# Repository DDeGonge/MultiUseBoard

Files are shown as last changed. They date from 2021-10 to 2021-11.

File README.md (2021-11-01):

# MultiUseBoard
The MUB - An ultra-compact, modular processing unit

## What is it?
A tiny, modular, all-in-one processing board. On it's own, it can't do much. But this board can be integrated into just about any other board. All of the mcu pins and power lines are accessible through the low-profile connectors, providing the maximum mcu potential for any project.

## So what makes this better than an Arduino/Blue Pill/Feather?
Well, a few reasons...
- Super compact 32mm x 23mm size
- Powerful Cortex M4 120MHz mcu
- Access to EVERY SINGLE PIN (41 total GPIO)
- Super tiny and low profile board-board connectors
- Onboard 5v and 3v3 regulators (Supports up to 32V input)
- $10 BOM cost at qty 1, $7 at qty 10
- Broken out programming header for easy access

## Cool, I want one!
Great! Then build it yourself :) I hope to sell these boards once the global chip shortage resolves itself, but for now you are on your own!

The gerber files to order the board are found in this repo. Order at your own risk.

A probably up-to-date BOM can be found [here](https://octopart.com/bom-tool/H8oUqADt)

A custom package for kicad exists in the libraries folder, so you can easily integrate the mounting footprint into your own board and simply connect a MUB in the slot.

Godspeed.

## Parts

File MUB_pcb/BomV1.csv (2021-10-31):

Id | Designator | Package | Quantity | Designation | Supplier and ref
1 | J3 | PinHeader_1x05_P1.27mm_Vertical | 1 | Conn_01x05
2 | R3 | R_0402_1005Metric | 1 | 0
3 | G*** | logo_v1 | 1 | LOGO
4 | C35,C12,C36,C2 | C_0805_2012Metric | 4 | 10uF
5 | C13,C3,C11,C10,C7 | C_0603_1608Metric | 5 | 1uF
6 | C8,C25,C9,C6,C5,C4,C1 | C_0603_1608Metric | 7 | 100nF
7 | R15,R1,R2 | R_0603_1608Metric | 3 | 10k
8 | J4 | AMPHENOL_10118194-0001LF | 1 | 10118194-0001LF
9 | IC2 | QFN-64-1EP_9x9mm_P0.5mm_EP6x6mm | 1 | ATSAMD51J19A-MU
10 | J2,J1 | DF40C40DP04V51 | 2 | DF40C-40DP-0.4V_51_
11 | S1 | KMR421GULCLFS | 1 | KMR243GLFG
12 | R20,R19,R17 | R_0603_1608Metric | 3 | 174
13 | D2,D1 | LED_0603_1608Metric | 2 | LED
14 | Y1 | LFXTAL009678REEL | 1 | LFXTAL009678REEL
15 | U3 | SOT-23-5 | 1 | AP2112K-3.3
16 | R18,R16 | R_0603_1608Metric | 2 | 2k2
17 | L3,L2,L1 | L_0805_2012Metric | 3 | 10uH
18 | IC1 | SOT95P280X100-6N | 1 | AP63205WU-7
19 | D5 | D_SOD-123F | 1 | CGRTS4004-HF
20 | C33,C32 | C_0603_1608Metric | 2 | 12pF

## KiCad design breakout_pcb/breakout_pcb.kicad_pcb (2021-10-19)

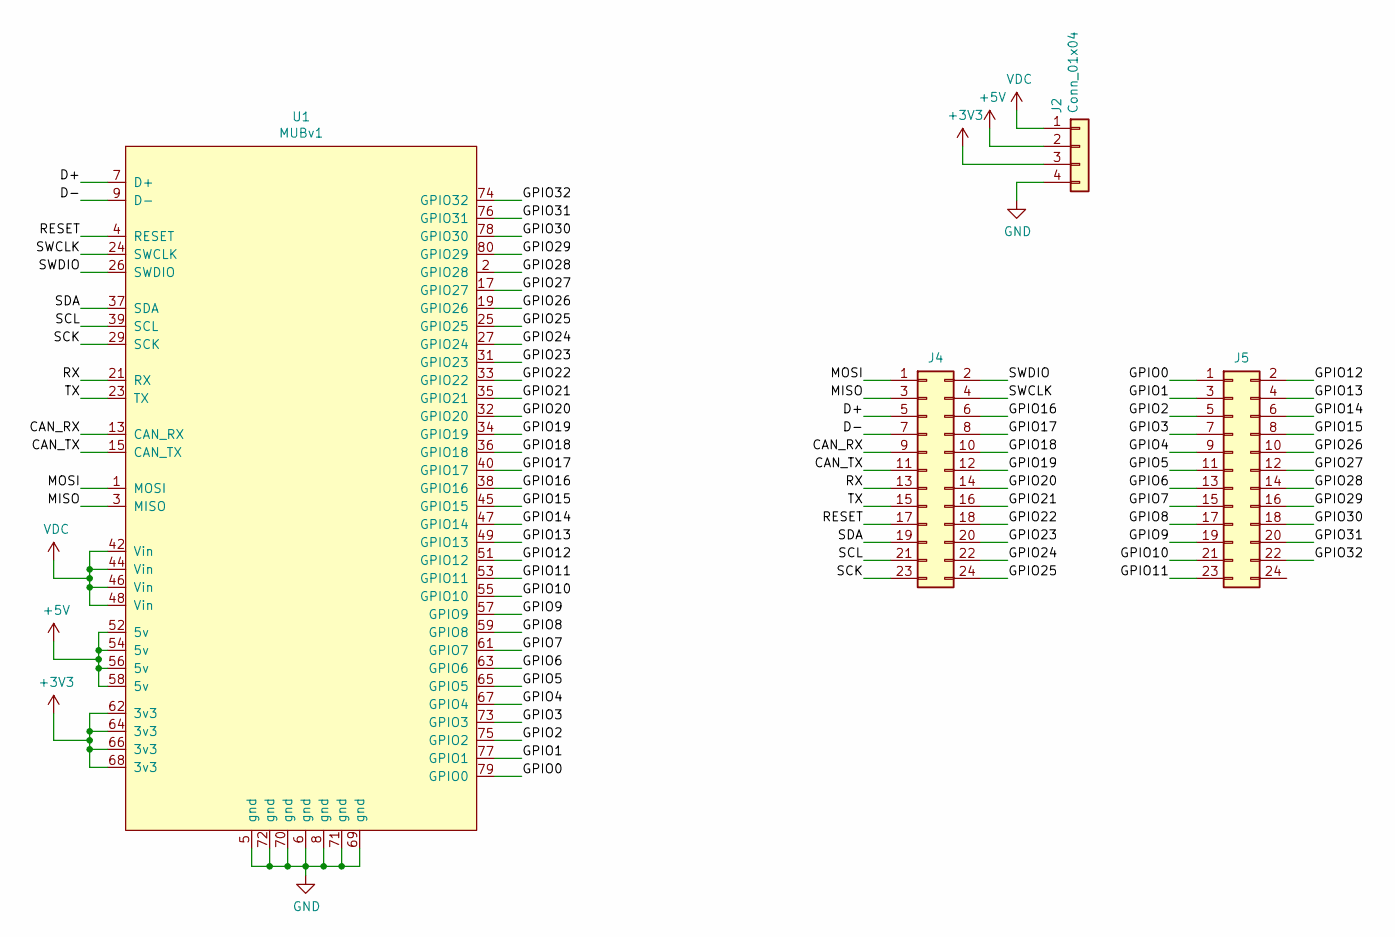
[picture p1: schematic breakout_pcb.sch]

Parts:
J2: Conn_01x04; PinSocket_1x04_P2.54mm_Vertical
J4, J5: Conn_02x12_Odd_Even; PinSocket_2x12_P2.54mm_Vertical
U1: MUBv1; MUB_v1

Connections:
+3V3: J2.3, U1.62 (3v3), U1.64 (3v3), U1.66 (3v3), U1.68 (3v3)
+5V: J2.2, U1.52 (5v), U1.54 (5v), U1.56 (5v), U1.58 (5v)
/CAN_RX: J4.9, U1.13 (CAN_RX)
/CAN_TX: J4.11, U1.15 (CAN_TX)
/D+: J4.5, U1.7 (D+)
/D-: J4.7, U1.9 (D-)
/GPIO0: J5.1, U1.79 (GPIO0)
/GPIO1: J5.3, U1.77 (GPIO1)
/GPIO2: J5.5, U1.75 (GPIO2)
/GPIO3: J5.7, U1.73 (GPIO3)
/GPIO4: J5.9, U1.67 (GPIO4)
/GPIO5: J5.11, U1.65 (GPIO5)
/GPIO6: J5.13, U1.63 (GPIO6)
/GPIO7: J5.15, U1.61 (GPIO7)
/GPIO8: J5.17, U1.59 (GPIO8)
/GPIO9: J5.19, U1.57 (GPIO9)
/GPIO10: J5.21, U1.55 (GPIO10)
/GPIO11: J5.23, U1.53 (GPIO11)
/GPIO12: J5.2, U1.51 (GPIO12)
/GPIO13: J5.4, U1.49 (GPIO13)
/GPIO14: J5.6, U1.47 (GPIO14)
/GPIO15: J5.8, U1.45 (GPIO15)
/GPIO16: J4.6, U1.38 (GPIO16)
/GPIO17: J4.8, U1.40 (GPIO17)
/GPIO18: J4.10, U1.36 (GPIO18)
/GPIO19: J4.12, U1.34 (GPIO19)
/GPIO20: J4.14, U1.32 (GPIO20)
/GPIO21: J4.16, U1.35 (GPIO21)
/GPIO22: J4.18, U1.33 (GPIO22)
/GPIO23: J4.20, U1.31 (GPIO23)
/GPIO24: J4.22, U1.27 (GPIO24)
/GPIO25: J4.24, U1.25 (GPIO25)
/GPIO26: J5.10, U1.19 (GPIO26)
/GPIO27: J5.12, U1.17 (GPIO27)
/GPIO28: J5.14, U1.2 (GPIO28)
/GPIO29: J5.16, U1.80 (GPIO29)
/GPIO30: J5.18, U1.78 (GPIO30)
/GPIO31: J5.20, U1.76 (GPIO31)
/GPIO32: J5.22, U1.74 (GPIO32)
/MISO: J4.3, U1.3 (MISO)
/MOSI: J4.1, U1.1 (MOSI)
/RESET: J4.17, U1.4 (RESET)
/RX: J4.13, U1.21 (RX)
/SCK: J4.23, U1.29 (SCK)
/SCL: J4.21, U1.39 (SCL)
/SDA: J4.19, U1.37 (SDA)
/SWCLK: J4.4, U1.24 (SWCLK)
/SWDIO: J4.2, U1.26 (SWDIO)
/TX: J4.15, U1.23 (TX)
GND: J2.4, U1.5 (gnd), U1.6 (gnd), U1.8 (gnd), U1.69 (gnd), U1.70 (gnd), U1.71 (gnd), U1.72 (gnd)
VDC: J2.1, U1.42 (Vin), U1.44 (Vin), U1.46 (Vin), U1.48 (Vin)

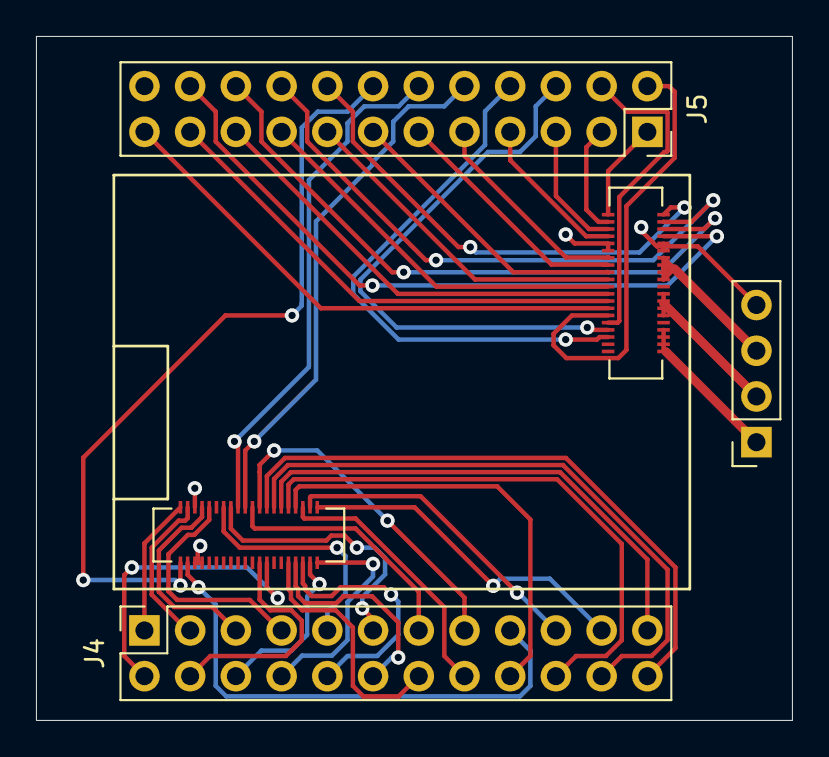
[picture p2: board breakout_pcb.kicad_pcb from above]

Board: 2 copper layers, 42.0 x 38.0 mm, 4 parts (0 on the bottom side), 51 nets.

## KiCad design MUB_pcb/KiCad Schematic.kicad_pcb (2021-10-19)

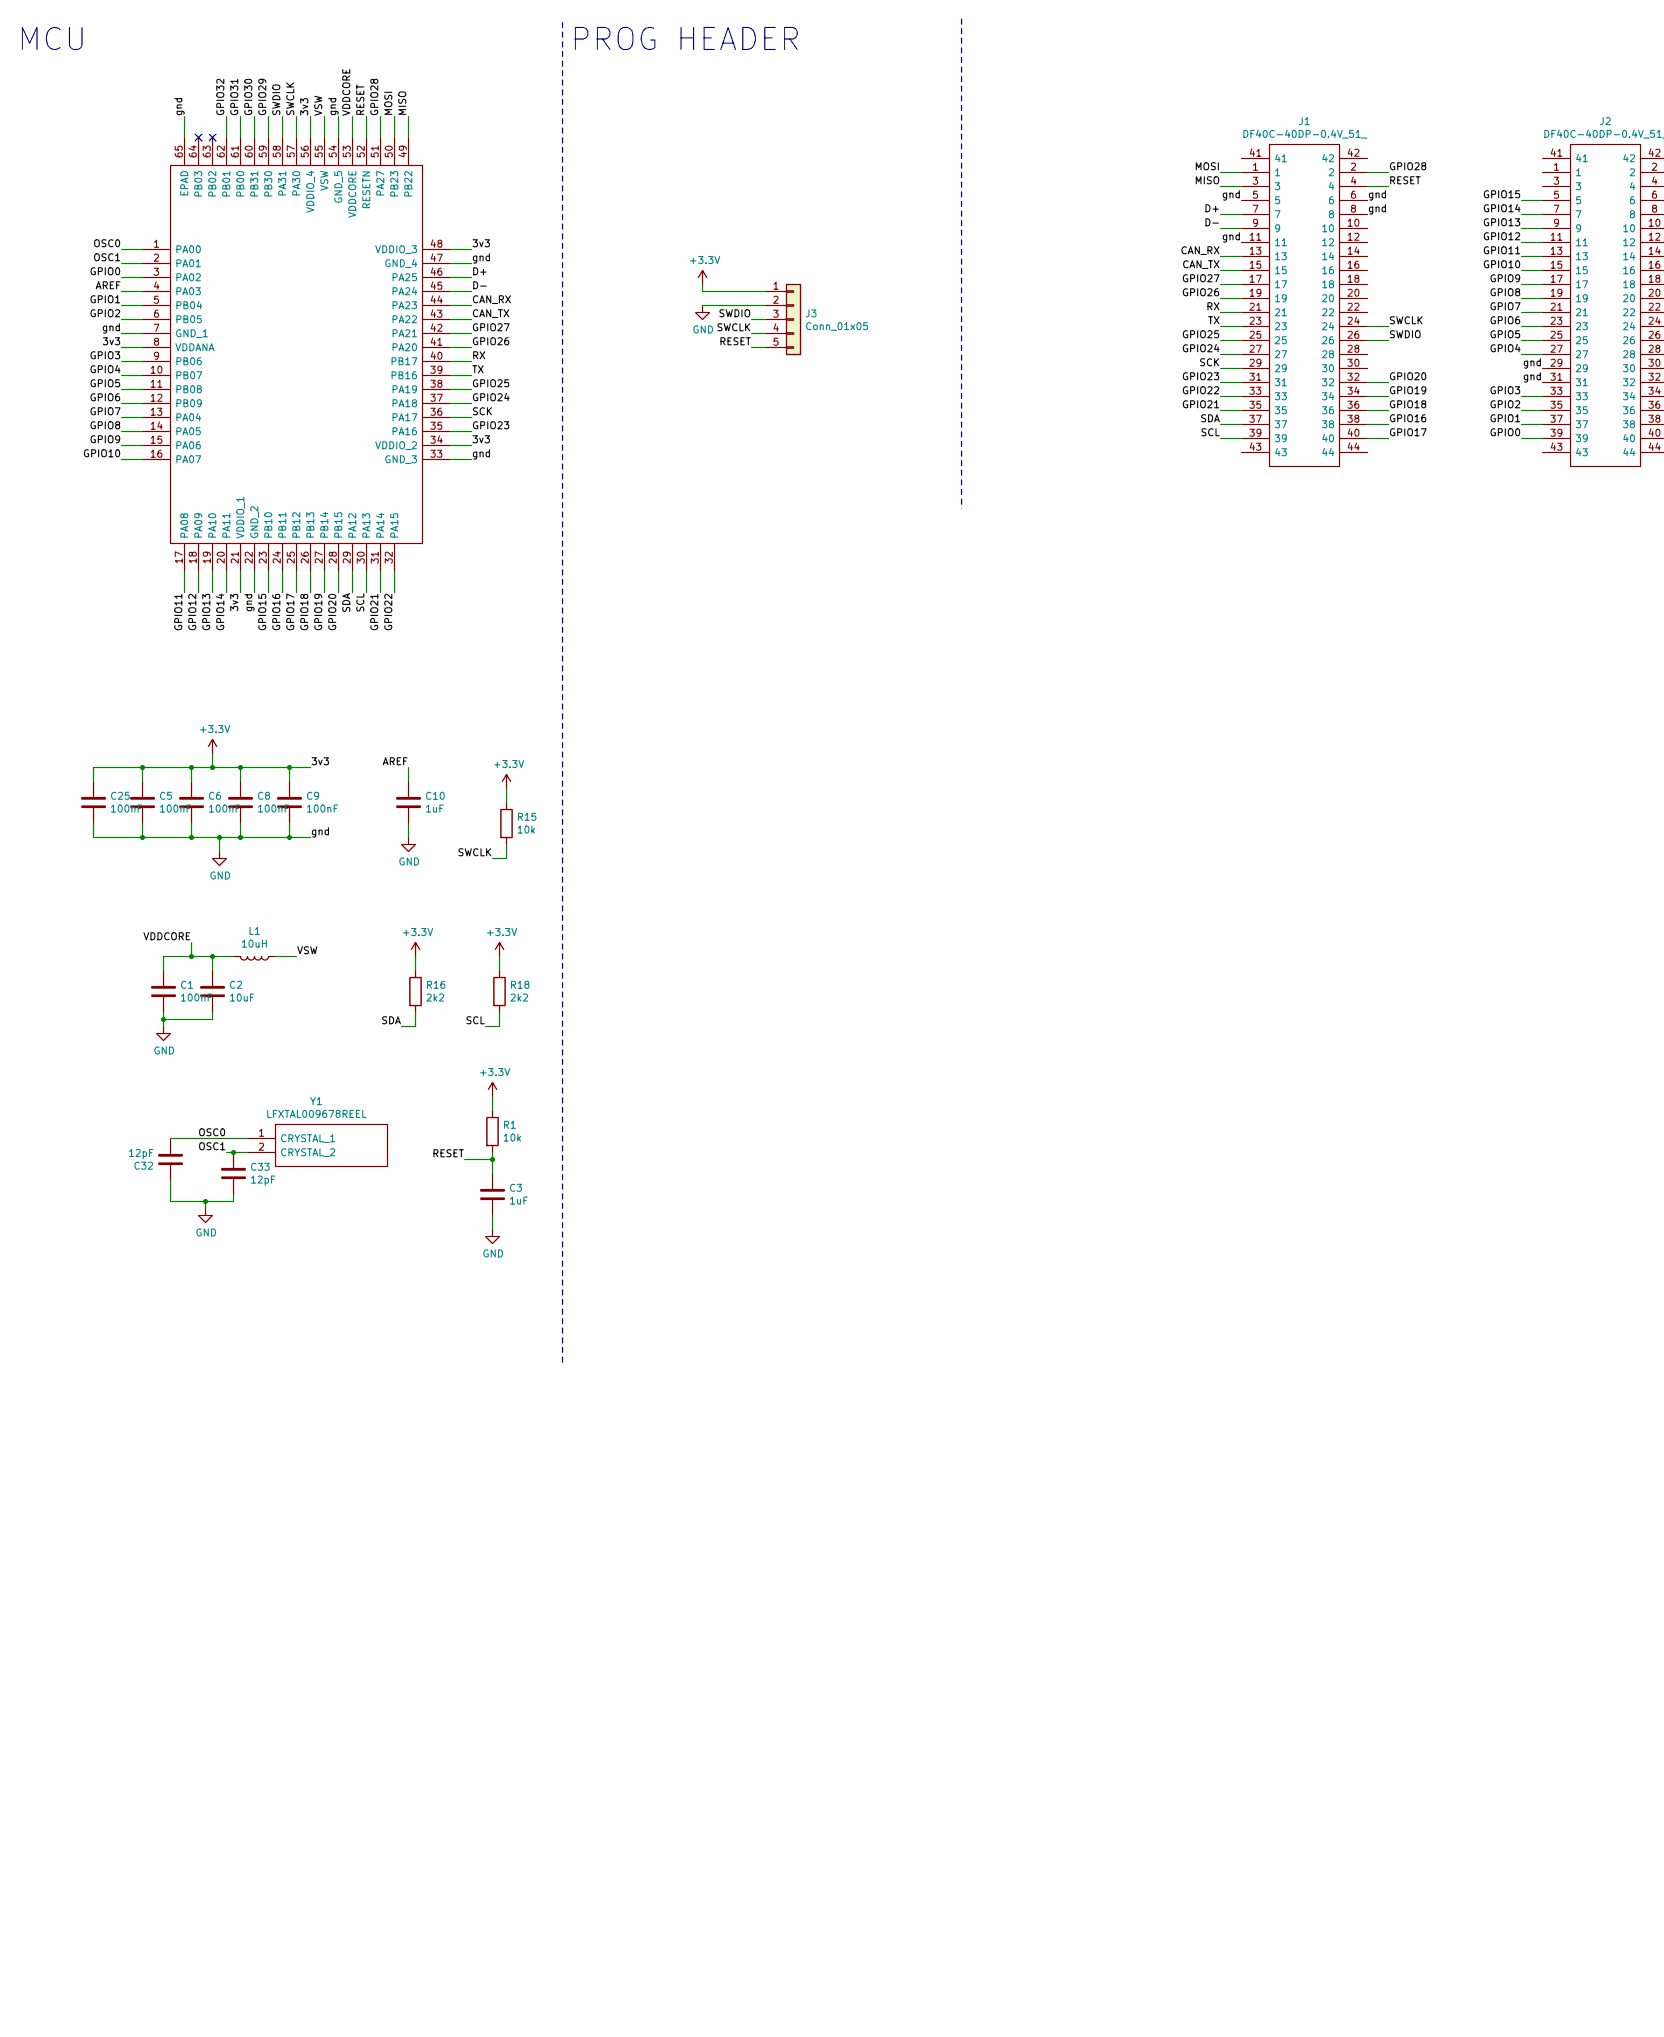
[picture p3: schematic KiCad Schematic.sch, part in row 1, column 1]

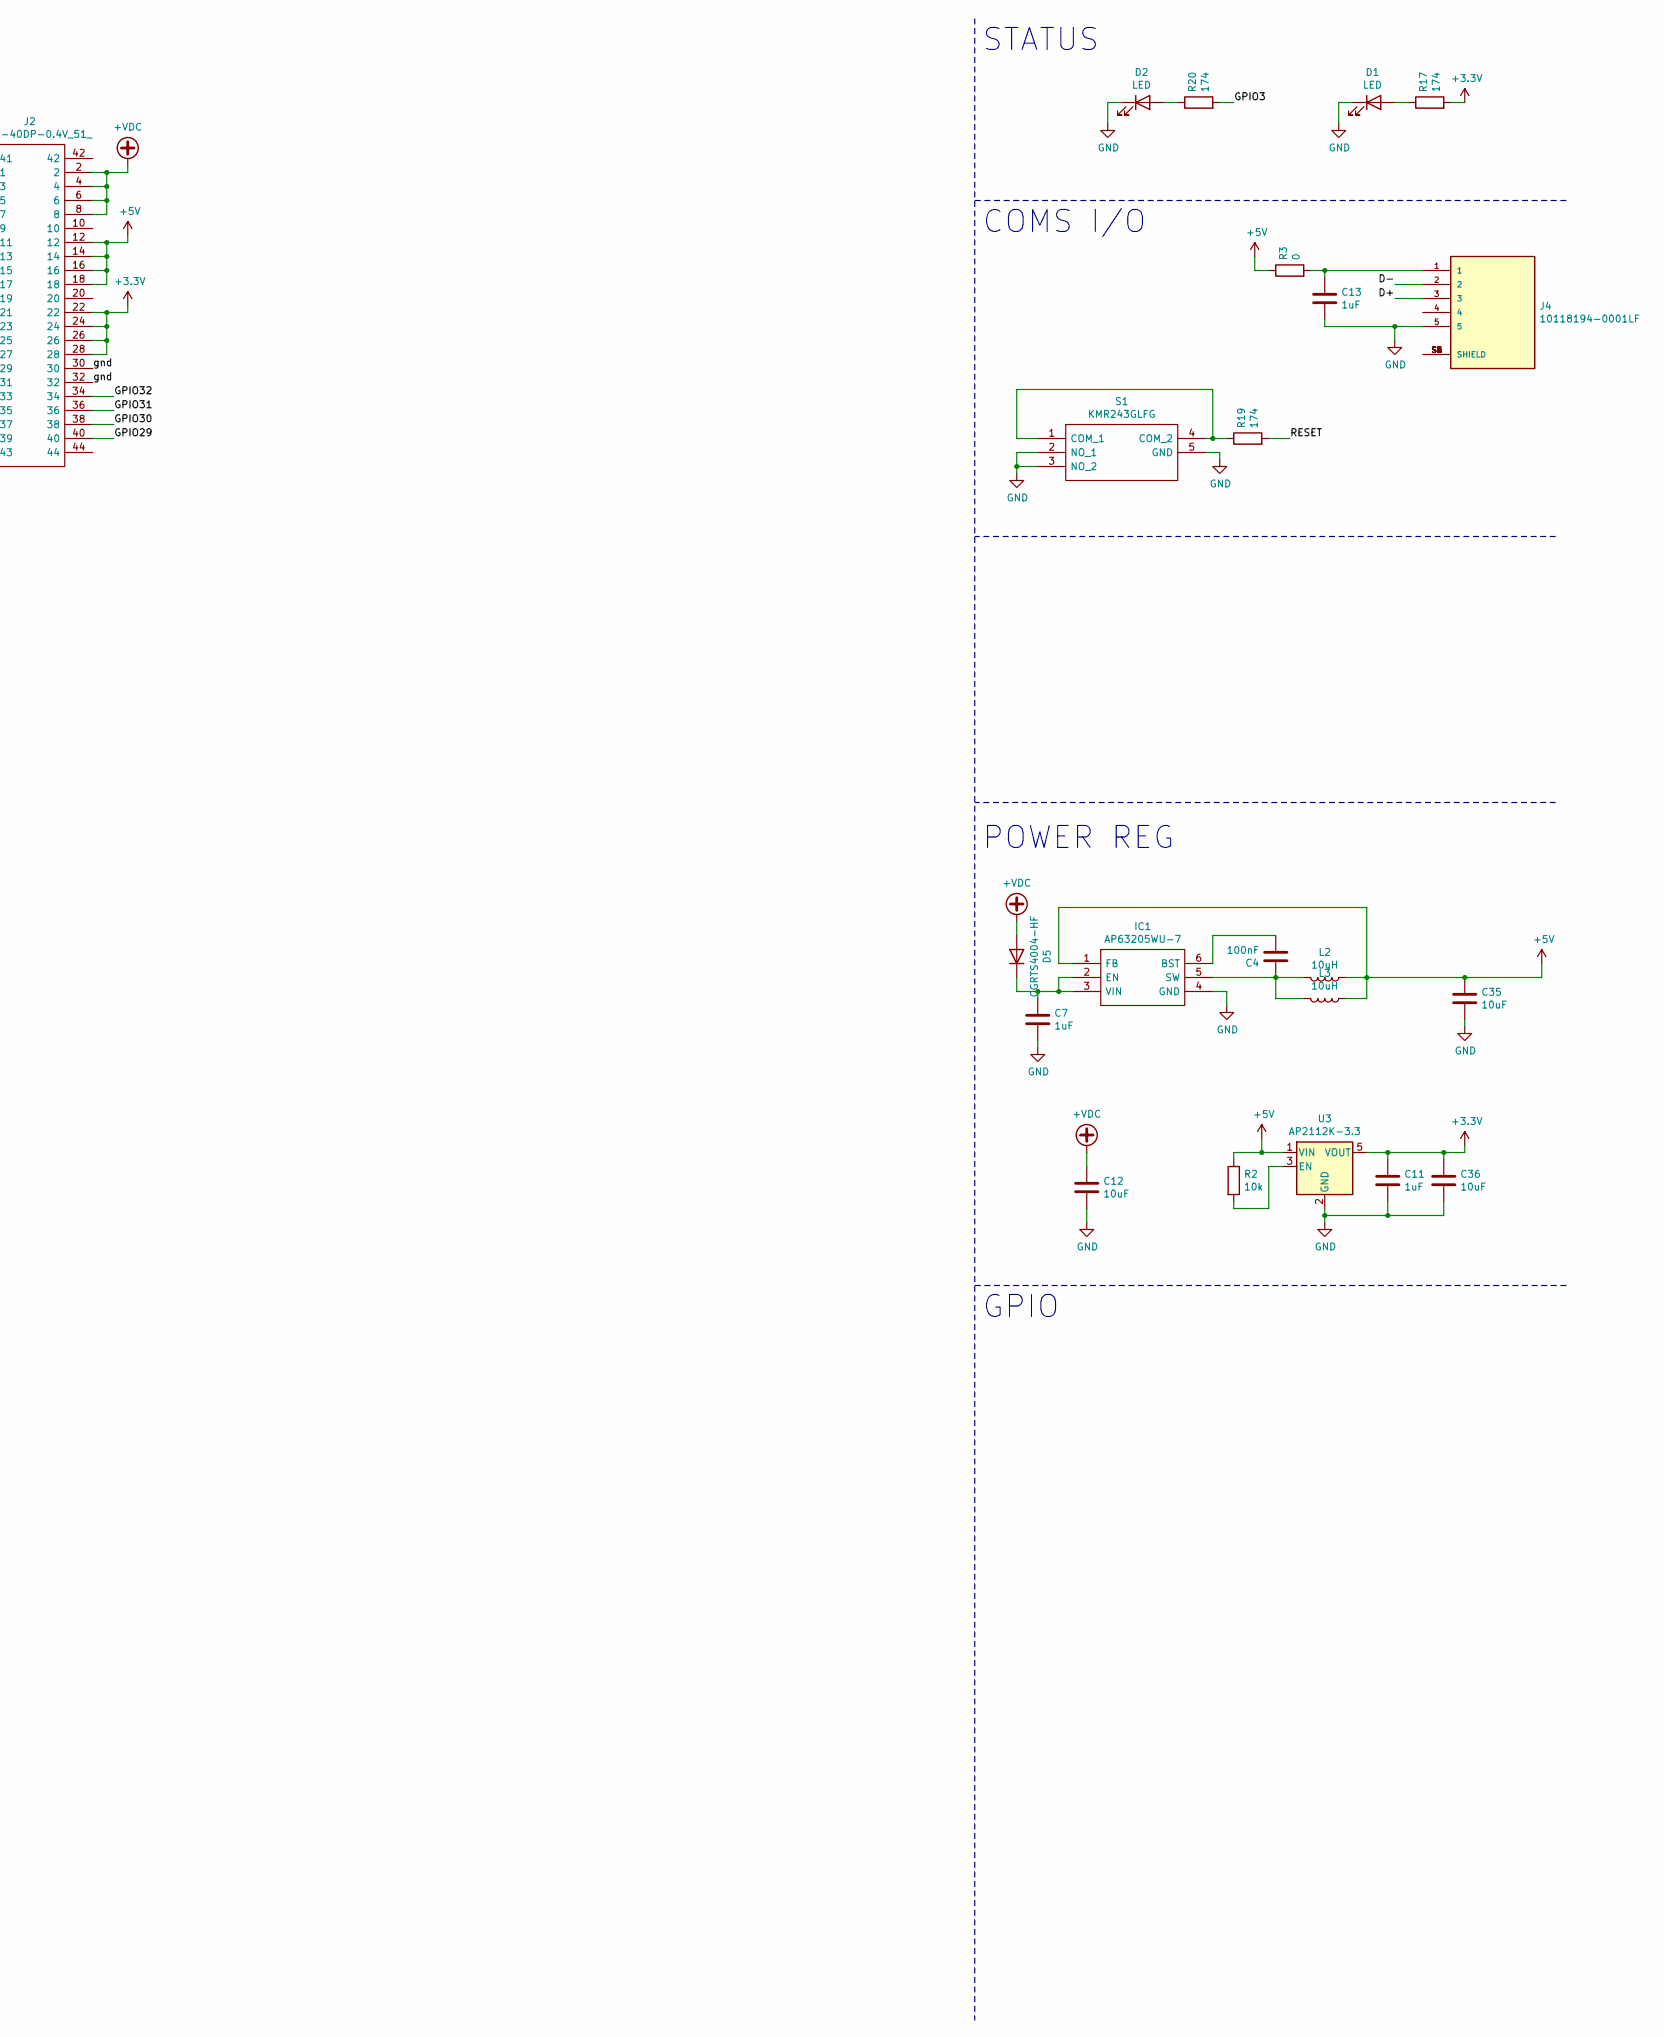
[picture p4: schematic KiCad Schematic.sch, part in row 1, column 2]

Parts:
C1, C4, C5, C6, C8, C9, C25: 100nF; C_0603_1608Metric
C2, C12, C35, C36: 10uF; C_0805_2012Metric
C3, C7, C10, C11, C13: 1uF; C_0603_1608Metric
C32, C33: 12pF; C_0603_1608Metric
D1, D2: LED; LED_0603_1608Metric
D5: CGRTS4004-HF; D_SOD-123F
IC1: AP63205WU-7; SOT95P280X100-6N; Mouser Part Number 621-AP63205WU-7
IC2: ATSAMD51J19A-MU; QFN-64-1EP_9x9mm_P0.5mm_EP6x6mm_ThermalVias; Mouser Part Number 556-ATSAMD51J19AMU
J1, J2: DF40C-40DP-0.4V_51_; DF40C40DP04V51; Manufacturer_Part_Number DF40C-40DP-0.4V(51); Mouser Part Number 798-DF40C40DP0.4V51
J3: Conn_01x05; PinHeader_1x05_P1.27mm_Vertical
J4: 10118194-0001LF; AMPHENOL_10118194-0001LF
L1, L2, L3: 10uH; L_0805_2012Metric
R1, R2, R15: 10k; R_0603_1608Metric
R3: 0; R_0402_1005Metric
R16, R18: 2k2; R_0603_1608Metric
R17, R19, R20: 174; R_0603_1608Metric
S1: KMR243GLFG; KMR421GULCLFS; Mouser Part Number 611-KMR243GLFG
U3: AP2112K-3.3; SOT-23-5
Y1: LFXTAL009678REEL; Mouser Part Number 449-LFXTAL009678REEL

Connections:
+3V3: C5.1, C6.1, C8.1, C9.1, C11.1, C25.1, C36.1, IC2.8 (VDDANA), IC2.21 (VDDIO_1), IC2.34 (VDDIO_2), IC2.48 (VDDIO_3), IC2.56 (VDDIO_4), J2.22, J2.24, J2.26, J2.28, J3.1, R1.1, R15.1, R16.1, R17.2, R18.1, U3.5 (VOUT)
+5V: C35.1, IC1.1 (FB), J2.12, J2.14, J2.16, J2.18, L2.1, L3.1, R2.1, R3.1, U3.1 (VIN)
+VDC: C12.1, D5.2 (A), J2.2, J2.4, J2.6, J2.8
/AREF: C10.1, IC2.4 (PA03)
/CAN_RX: IC2.44 (PA23), J1.13
/CAN_TX: IC2.43 (PA22), J1.15
/D+: IC2.46 (PA25), J1.7, J4.3
/D-: IC2.45 (PA24), J1.9, J4.2
/GPIO0: IC2.3 (PA02), J2.39
/GPIO1: IC2.5 (PB04), J2.37
/GPIO2: IC2.6 (PB05), J2.35
/GPIO3: IC2.9 (PB06), J2.33, R20.2
/GPIO4: IC2.10 (PB07), J2.27
/GPIO5: IC2.11 (PB08), J2.25
/GPIO6: IC2.12 (PB09), J2.23
/GPIO7: IC2.13 (PA04), J2.21
/GPIO8: IC2.14 (PA05), J2.19
/GPIO9: IC2.15 (PA06), J2.17
/GPIO10: IC2.16 (PA07), J2.15
/GPIO11: IC2.17 (PA08), J2.13
/GPIO12: IC2.18 (PA09), J2.11
/GPIO13: IC2.19 (PA10), J2.9
/GPIO14: IC2.20 (PA11), J2.7
/GPIO15: IC2.23 (PB10), J2.5
/GPIO16: IC2.24 (PB11), J1.38
/GPIO17: IC2.25 (PB12), J1.40
/GPIO18: IC2.26 (PB13), J1.36
/GPIO19: IC2.27 (PB14), J1.34
/GPIO20: IC2.28 (PB15), J1.32
/GPIO21: IC2.31 (PA14), J1.35
/GPIO22: IC2.32 (PA15), J1.33
/GPIO23: IC2.35 (PA16), J1.31
/GPIO24: IC2.37 (PA18), J1.27
/GPIO25: IC2.38 (PA19), J1.25
/GPIO26: IC2.41 (PA20), J1.19
/GPIO27: IC2.42 (PA21), J1.17
/GPIO28: IC2.51 (PA27), J1.2
/GPIO29: IC2.59 (PB30), J2.40
/GPIO30: IC2.60 (PB31), J2.38
/GPIO31: IC2.61 (PB00), J2.36
/GPIO32: IC2.62 (PB01), J2.34
/MISO: IC2.49 (PB22), J1.3
/MOSI: IC2.50 (PB23), J1.1
/OSC0: C32.2, IC2.1 (PA00), Y1.1 (CRYSTAL_1)
/OSC1: C33.1, IC2.2 (PA01), Y1.2 (CRYSTAL_2)
/RESET: C3.1, IC2.52 (RESETN), J1.4, J3.5, R1.2, R19.2
/RX: IC2.40 (PB17), J1.21
/SCK: IC2.36 (PA17), J1.29
/SCL: IC2.30 (PA13), J1.39, R18.2
/SDA: IC2.29 (PA12), J1.37, R16.2
/SWCLK: IC2.57 (PA30), J1.24, J3.4, R15.2
/SWDIO: IC2.58 (PA31), J1.26, J3.3
/TX: IC2.39 (PB16), J1.23
/VDDCORE: C1.1, C2.1, IC2.53 (VDDCORE), L1.2
/VSW: IC2.55 (VSW), L1.1
GND: C1.2, C2.2, C3.2, C5.2, C6.2, C7.2, C8.2, C9.2, C10.2, C11.2, C12.2, C13.2, C25.2, C32.1, C33.2, C35.2, C36.2, D1.1 (K), D2.1 (K), IC1.4 (GND), IC2.7 (GND_1), IC2.22 (GND_2), IC2.33 (GND_3), IC2.47 (GND_4), IC2.54 (GND_5), IC2.65 (EPAD), J1.5, J1.6, J1.8, J1.11, J2.29, J2.30, J2.31, J2.32, J3.2, J4.5, S1.2 (NO_1), S1.3 (NO_2), S1.5 (GND), U3.2 (GND)
unnamed: C4.1, IC1.5 (SW), L2.2, L3.2
unnamed: C4.2, IC1.6 (BST)
unnamed: C7.1, D5.1 (K), IC1.2 (EN), IC1.3 (VIN)
unnamed: C13.1, J4.1, R3.2
unnamed: D1.2 (A), R17.1
unnamed: D2.2 (A), R20.1
unnamed: J4.S1 (SHIELD), J4.S2 (SHIELD), J4.S3 (SHIELD), J4.S4 (SHIELD), J4.S5 (SHIELD), J4.S6 (SHIELD)
unnamed: R2.2, U3.3 (EN)
unnamed: R19.1, S1.1 (COM_1), S1.4 (COM_2)

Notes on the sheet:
GPIO
POWER REG
COMS I/O
STATUS
PROG HEADER
MCU

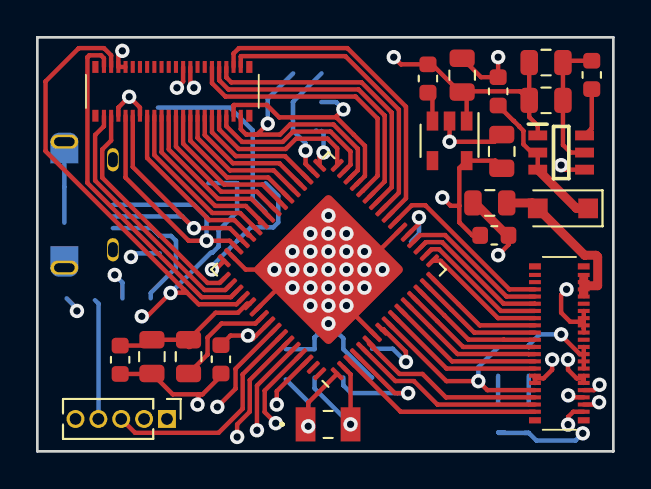
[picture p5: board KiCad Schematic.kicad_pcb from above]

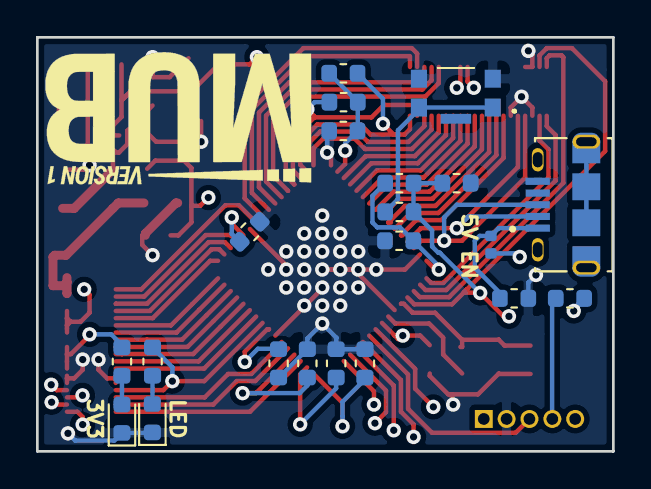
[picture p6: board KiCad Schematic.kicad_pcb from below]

Board: 4 copper layers, 32.0 x 23.0 mm, 42 parts (21 on the bottom side), 65 nets.

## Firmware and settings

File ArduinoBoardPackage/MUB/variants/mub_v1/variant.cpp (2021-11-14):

/*
  Copyright (c) 2014-2015 Arduino LLC.  All right reserved.

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
  You should have received a copy of the GNU Lesser General Public
  License along with this library; if not, write to the Free Software
  Foundation, Inc., 51 Franklin St, Fifth Floor, Boston, MA  02110-1301  USA
*/

#include "variant.h"

/*
 * Pins descriptions
 */

//TCC0 IOSET 6
//TCC1 IOSET 1
//TC0 IOSET 1
//TC1 IOSET 1
//TC2 IOSET 2
//TC3 IOSET 1
//TC4 IOSET 1
const PinDescription g_APinDescription[]=
{
  // 0..32 GPIO
  { PORTA,  2, PIO_DIGITAL, PIN_ATTR_NONE, No_ADC_Channel, NOT_ON_PWM, NOT_ON_TIMER, EXTERNAL_INT_NONE },
  { PORTB,  4, PIO_DIGITAL, PIN_ATTR_NONE, No_ADC_Channel, NOT_ON_PWM, NOT_ON_TIMER, EXTERNAL_INT_NONE },
  { PORTB,  5, PIO_DIGITAL, PIN_ATTR_NONE, No_ADC_Channel, NOT_ON_PWM, NOT_ON_TIMER, EXTERNAL_INT_NONE },
  { PORTB,  6, PIO_DIGITAL, PIN_ATTR_NONE, No_ADC_Channel, NOT_ON_PWM, NOT_ON_TIMER, EXTERNAL_INT_NONE },
  { PORTB, 7,  PIO_DIGITAL, PIN_ATTR_NONE, No_ADC_Channel, NOT_ON_PWM, NOT_ON_TIMER, EXTERNAL_INT_NONE },
  { PORTB, 8,  PIO_DIGITAL, PIN_ATTR_NONE, No_ADC_Channel, NOT_ON_PWM, NOT_ON_TIMER, EXTERNAL_INT_NONE },
  { PORTB, 9,  PIO_ANALOG, (PIN_ATTR_ANALOG|PIN_ATTR_PWM_E), ADC_Channel3, TC4_CH1, TC4_CH1, EXTERNAL_INT_9 },
  { PORTA,  4, PIO_ANALOG, (PIN_ATTR_ANALOG|PIN_ATTR_PWM_E), ADC_Channel4, TC0_CH0, TC0_CH0, EXTERNAL_INT_4 },
  { PORTA,  5, PIO_ANALOG, (PIN_ATTR_ANALOG|PIN_ATTR_PWM_E), ADC_Channel5, TC0_CH1, TC0_CH1, EXTERNAL_INT_5 },
  { PORTA,  6, PIO_ANALOG, (PIN_ATTR_ANALOG|PIN_ATTR_PWM_E), ADC_Channel6, TC1_CH0, TC1_CH0, EXTERNAL_INT_6 },
  { PORTA,  7, PIO_ANALOG, (PIN_ATTR_ANALOG|PIN_ATTR_PWM_E), ADC_Channel7, TC1_CH1, TC1_CH1, EXTERNAL_INT_7 },
  { PORTA,  8, PIO_DIGITAL, PIN_ATTR_NONE, No_ADC_Channel, NOT_ON_PWM, NOT_ON_TIMER, EXTERNAL_INT_NONE },
  { PORTA,  9, PIO_DIGITAL, PIN_ATTR_NONE, No_ADC_Channel, NOT_ON_PWM, NOT_ON_TIMER, EXTERNAL_INT_NONE },
  { PORTA, 10, PIO_DIGITAL, PIN_ATTR_NONE, No_ADC_Channel, NOT_ON_PWM, NOT_ON_TIMER, EXTERNAL_INT_NONE },
  { PORTA, 11, PIO_DIGITAL, PIN_ATTR_NONE, No_ADC_Channel, NOT_ON_PWM, NOT_ON_TIMER, EXTERNAL_INT_NONE },
  { PORTB, 10, PIO_DIGITAL, PIN_ATTR_NONE, No_ADC_Channel, NOT_ON_PWM, NOT_ON_TIMER, EXTERNAL_INT_10 },
  { PORTB, 11, PIO_DIGITAL, PIN_ATTR_NONE, No_ADC_Channel, NOT_ON_PWM, NOT_ON_TIMER, EXTERNAL_INT_11 },
  { PORTB, 12, PIO_DIGITAL, PIN_ATTR_NONE, No_ADC_Channel, NOT_ON_PWM, NOT_ON_TIMER, EXTERNAL_INT_12 },
  { PORTB, 13, PIO_DIGITAL, PIN_ATTR_NONE, No_ADC_Channel, NOT_ON_PWM, NOT_ON_TIMER, EXTERNAL_INT_13 },
  { PORTB, 14, PIO_DIGITAL, PIN_ATTR_NONE, No_ADC_Channel, NOT_ON_PWM, NOT_ON_TIMER, EXTERNAL_INT_14 },
  { PORTB, 15, PIO_DIGITAL, PIN_ATTR_NONE, No_ADC_Channel, NOT_ON_PWM, NOT_ON_TIMER, EXTERNAL_INT_15 },
  { PORTA, 14, PIO_DIGITAL, PIN_ATTR_NONE, No_ADC_Channel, NOT_ON_PWM, NOT_ON_TIMER, EXTERNAL_INT_NONE },
  { PORTA, 15, PIO_DIGITAL, PIN_ATTR_NONE, No_ADC_Channel, NOT_ON_PWM, NOT_ON_TIMER, EXTERNAL_INT_NONE },
  { PORTA, 16, PIO_DIGITAL, PIN_ATTR_NONE, No_ADC_Channel, NOT_ON_PWM, NOT_ON_TIMER, EXTERNAL_INT_NONE },
  { PORTA, 18, PIO_DIGITAL, PIN_ATTR_NONE, No_ADC_Channel, NOT_ON_PWM, NOT_ON_TIMER, EXTERNAL_INT_NONE },
  { PORTA, 19, PIO_DIGITAL, PIN_ATTR_NONE, No_ADC_Channel, NOT_ON_PWM, NOT_ON_TIMER, EXTERNAL_INT_NONE },
  { PORTA, 20, PIO_DIGITAL, PIN_ATTR_NONE, No_ADC_Channel, NOT_ON_PWM, NOT_ON_TIMER, EXTERNAL_INT_NONE },
  { PORTA, 21, PIO_DIGITAL, PIN_ATTR_NONE, No_ADC_Channel, NOT_ON_PWM, NOT_ON_TIMER, EXTERNAL_INT_NONE },
  { PORTA, 27, PIO_DIGITAL, PIN_ATTR_NONE, No_ADC_Channel, NOT_ON_PWM, NOT_ON_TIMER, EXTERNAL_INT_NONE },
  { PORTB, 30, PIO_DIGITAL, PIN_ATTR_NONE, No_ADC_Channel, NOT_ON_PWM, NOT_ON_TIMER, EXTERNAL_INT_NONE },
  { PORTB, 31, PIO_DIGITAL, PIN_ATTR_NONE, No_ADC_Channel, NOT_ON_PWM, NOT_ON_TIMER, EXTERNAL_INT_NONE },
  { PORTB,  0, PIO_DIGITAL, PIN_ATTR_NONE, No_ADC_Channel, NOT_ON_PWM, NOT_ON_TIMER, EXTERNAL_INT_NONE },
  { PORTB,  1, PIO_DIGITAL, PIN_ATTR_NONE, No_ADC_Channel, NOT_ON_PWM, NOT_ON_TIMER, EXTERNAL_INT_NONE },

  // 33 (AREF)
  { PORTA, 3, PIO_ANALOG, PIN_ATTR_ANALOG, No_ADC_Channel, NOT_ON_PWM, NOT_ON_TIMER, EXTERNAL_INT_NONE }, // DAC/VREFP

  // 34..35 - I2C pins (SDA/SCL)
  { PORTA, 12, PIO_SERCOM, PIN_ATTR_PWM_E, No_ADC_Channel, TC2_CH0, TC2_CH0, EXTERNAL_INT_12 }, // SDA: SERCOM2/PAD[0]
  { PORTA, 13, PIO_SERCOM, PIN_ATTR_PWM_E, No_ADC_Channel, TC2_CH1, TC2_CH1, EXTERNAL_INT_13 }, // SCL: SERCOM2/PAD[1]

  // 36..38 - SPI pins (MISO,MOSI,SCK)
  { PORTB, 22, PIO_SERCOM, PIN_ATTR_DIGITAL, No_ADC_Channel, NOT_ON_PWM, NOT_ON_TIMER, EXTERNAL_INT_6 }, // MISO: SERCOM1/PAD[2]
  { PORTB, 23, PIO_SERCOM, PIN_ATTR_DIGITAL, No_ADC_Channel, NOT_ON_PWM, NOT_ON_TIMER, EXTERNAL_INT_7 }, // MOSI: SERCOM1/PAD[3]
  { PORTA, 17, PIO_SERCOM, PIN_ATTR_DIGITAL, No_ADC_Channel, NOT_ON_PWM, NOT_ON_TIMER, EXTERNAL_INT_1 }, // SCK: SERCOM1/PAD[1]

  // 39..40 - SERCOM/UART (Serial1)
  { PORTB, 17, PIO_SERCOM, PIN_ATTR_PWM_G, No_ADC_Channel, TCC0_CH4, NOT_ON_TIMER, EXTERNAL_INT_1 }, // RX: SERCOM5/PAD[1]
  { PORTB, 16, PIO_SERCOM, PIN_ATTR_PWM_G, No_ADC_Channel, TCC0_CH5, NOT_ON_TIMER, EXTERNAL_INT_0 }, // TX: SERCOM5/PAD[0]

  // 41..42 - CAN (RX,TX)
  { PORTA, 23, PIO_DIGITAL, PIN_ATTR_NONE, No_ADC_Channel, NOT_ON_PWM, NOT_ON_TIMER, EXTERNAL_INT_NONE }, // RX
  { PORTA, 22, PIO_DIGITAL, PIN_ATTR_NONE, No_ADC_Channel, NOT_ON_PWM, NOT_ON_TIMER, EXTERNAL_INT_NONE }, // TX

  // 43..45 - USB
  { NOT_A_PORT, 0, PIO_NOT_A_PIN, PIN_ATTR_NONE, No_ADC_Channel, NOT_ON_PWM, NOT_ON_TIMER, EXTERNAL_INT_NONE }, // USB Host enable DOES NOT EXIST ON THIS BOARD
  { PORTA, 24, PIO_COM, PIN_ATTR_NONE, No_ADC_Channel, NOT_ON_PWM, NOT_ON_TIMER, EXTERNAL_INT_NONE }, // USB/DM
  { PORTA, 27, PIO_COM, PIN_ATTR_NONE, No_ADC_Channel, NOT_ON_PWM, NOT_ON_TIMER, EXTERNAL_INT_NONE } // USB/DP
} ;

const void* g_apTCInstances[TCC_INST_NUM+TC_INST_NUM]={ TCC0, TCC1, TCC2, TCC3, TCC4, TC0, TC1, TC2, TC3, TC4, TC5 } ;
const uint32_t GCLK_CLKCTRL_IDs[TCC_INST_NUM+TC_INST_NUM] = { TCC0_GCLK_ID, TCC1_GCLK_ID, TCC2_GCLK_ID, TCC3_GCLK_ID, TCC4_GCLK_ID, TC0_GCLK_ID, TC1_GCLK_ID, TC2_GCLK_ID, TC3_GCLK_ID, TC4_GCLK_ID, TC5_GCLK_ID } ;

// Multi-serial objects instantiation
SERCOM sercom0( SERCOM0 ) ;
SERCOM sercom1( SERCOM1 ) ;
SERCOM sercom2( SERCOM2 ) ;
SERCOM sercom3( SERCOM3 ) ;
SERCOM sercom4( SERCOM4 ) ;
SERCOM sercom5( SERCOM5 ) ;

Uart Serial1( &sercom5, PIN_SERIAL1_RX, PIN_SERIAL1_TX, PAD_SERIAL1_RX, PAD_SERIAL1_TX ) ;

void SERCOM5_0_Handler()
{
  Serial1.IrqHandler();
}
void SERCOM5_1_Handler()
{
  Serial1.IrqHandler();
}
void SERCOM5_2_Handler()
{
  Serial1.IrqHandler();
}
void SERCOM5_3_Handler()
{
  Serial1.IrqHandler();
}

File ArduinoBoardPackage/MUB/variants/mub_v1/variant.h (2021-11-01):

/*
  Copyright (c) 2014-2015 Arduino LLC.  All right reserved.

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
  You should have received a copy of the GNU Lesser General Public
  License along with this library; if not, write to the Free Software
  Foundation, Inc., 51 Franklin St, Fifth Floor, Boston, MA  02110-1301  USA
*/

#ifndef _VARIANT_FEATHER_M4_
#define _VARIANT_FEATHER_M4_

// The definitions here needs a SAMD core >=1.6.10
#define ARDUINO_SAMD_VARIANT_COMPLIANCE 10610

/*----------------------------------------------------------------------------
 *        Definitions
 *----------------------------------------------------------------------------*/

/** Frequency of the board main oscillator */
#define VARIANT_MAINOSC		(32768ul)

/** Master clock frequency */
#define VARIANT_MCK        (F_CPU)

#define VARIANT_GCLK0_FREQ (F_CPU)
#define VARIANT_GCLK1_FREQ (48000000UL)
#define VARIANT_GCLK2_FREQ (100000000UL)

/*----------------------------------------------------------------------------
 *        Headers
 *----------------------------------------------------------------------------*/

#include "WVariant.h"

#ifdef __cplusplus
#include "SERCOM.h"
#include "Uart.h"
#endif // __cplusplus

#ifdef __cplusplus
extern "C"
{
#endif // __cplusplus

/*----------------------------------------------------------------------------
 *        Pins
 *----------------------------------------------------------------------------*/

// Number of pins defined in PinDescription array
#define PINS_COUNT           (54u)
#define NUM_DIGITAL_PINS     (34u)
#define NUM_ANALOG_INPUTS    (1u)
#define NUM_ANALOG_OUTPUTS   (1u)
#define analogInputToDigitalPin(p)  ((p < 6u) ? (p) + 14u : -1)

#define digitalPinToPort(P)        ( &(PORT->Group[g_APinDescription[P].ulPort]) )
#define digitalPinToBitMask(P)     ( 1 << g_APinDescription[P].ulPin )
//#define analogInPinToBit(P)        ( )
#define portOutputRegister(port)   ( &(port->OUT.reg) )
#define portInputRegister(port)    ( &(port->IN.reg) )
#define portModeRegister(port)     ( &(port->DIR.reg) )
#define digitalPinHasPWM(P)        ( g_APinDescription[P].ulPWMChannel != NOT_ON_PWM || g_APinDescription[P].ulTCChannel != NOT_ON_TIMER )

/*
 * digitalPinToTimer(..) is AVR-specific and is not defined for SAMD
 * architecture. If you need to check if a pin supports PWM you must
 * use digitalPinHasPWM(..).
 *
 * https://github.com/arduino/Arduino/issues/1833
 */
// #define digitalPinToTimer(P)

// LEDs
#define PIN_LED_3            (3u)
#define PIN_LED              PIN_LED_3
#define LED_BUILTIN          PIN_LED_3


/*
 * Analog pins
 */
#define PIN_A0               (6ul)
#define PIN_A1               (PIN_A0 + 1)

#define PIN_DAC0             PIN_A0
#define PIN_DAC1             PIN_A1

static const uint8_t A0  = PIN_A0;
static const uint8_t A1  = PIN_A1;

static const uint8_t DAC0 = PIN_DAC0;
static const uint8_t DAC1 = PIN_DAC1;

#define ADC_RESOLUTION		12


// Other pins
#define PIN_ATN              (33ul)
static const uint8_t ATN = PIN_ATN;

/*
 * Serial interfaces
 */

// Serial1
#define PIN_SERIAL1_RX       (39ul)
#define PIN_SERIAL1_TX       (40ul)
#define PAD_SERIAL1_RX       (SERCOM_RX_PAD_1)
#define PAD_SERIAL1_TX       (UART_TX_PAD_0)

/*
 * SPI Interfaces
 */
#define SPI_INTERFACES_COUNT 1

#define PIN_SPI_MISO         (36u)
#define PIN_SPI_MOSI         (37u)
#define PIN_SPI_SCK          (38u)
#define PERIPH_SPI           sercom1
#define PAD_SPI_TX           SPI_PAD_3_SCK_1
#define PAD_SPI_RX           SERCOM_RX_PAD_2

static const uint8_t MOSI = PIN_SPI_MOSI ;
static const uint8_t MISO = PIN_SPI_MISO ;
static const uint8_t SCK  = PIN_SPI_SCK ;

/*
 * Wire Interfaces
 */
#define WIRE_INTERFACES_COUNT 1

#define PIN_WIRE_SDA         (34u)
#define PIN_WIRE_SCL         (35u)
#define PERIPH_WIRE          sercom2
#define WIRE_IT_HANDLER      SERCOM2_Handler
#define WIRE_IT_HANDLER_0    SERCOM2_0_Handler
#define WIRE_IT_HANDLER_1    SERCOM2_1_Handler
#define WIRE_IT_HANDLER_2    SERCOM2_2_Handler
#define WIRE_IT_HANDLER_3    SERCOM2_3_Handler

static const uint8_t SDA = PIN_WIRE_SDA;
static const uint8_t SCL = PIN_WIRE_SCL;

/*
 * USB
 */
#define PIN_USB_HOST_ENABLE (43ul)
#define PIN_USB_DM          (44ul)
#define PIN_USB_DP          (45ul)

/*
 * I2S Interfaces
 */
#define I2S_INTERFACES_COUNT 0

#define I2S_DEVICE          0
#define I2S_CLOCK_GENERATOR 3

#ifdef __cplusplus
}
#endif

/*----------------------------------------------------------------------------
 *        Arduino objects - C++ only
 *----------------------------------------------------------------------------*/

#ifdef __cplusplus

/*	=========================
 *	===== SERCOM DEFINITION
 *	=========================
*/
extern SERCOM sercom0;
extern SERCOM sercom1;
extern SERCOM sercom2;
extern SERCOM sercom3;
extern SERCOM sercom4;
extern SERCOM sercom5;

extern Uart Serial1;

#endif

// These serial port names are intended to allow libraries and architecture-neutral
// sketches to automatically default to the correct port name for a particular type
// of use.  For example, a GPS module would normally connect to SERIAL_PORT_HARDWARE_OPEN,
// the first hardware serial port whose RX/TX pins are not dedicated to another use.
//
// SERIAL_PORT_MONITOR        Port which normally prints to the Arduino Serial Monitor
//
// SERIAL_PORT_USBVIRTUAL     Port which is USB virtual serial
//
// SERIAL_PORT_LINUXBRIDGE    Port which connects to a Linux system via Bridge library
//
// SERIAL_PORT_HARDWARE       Hardware serial port, physical RX & TX pins.
//
// SERIAL_PORT_HARDWARE_OPEN  Hardware serial ports which are open for use.  Their RX & TX
//                            pins are NOT connected to anything by default.
#define SERIAL_PORT_USBVIRTUAL      Serial
#define SERIAL_PORT_MONITOR         Serial
// Serial has no physical pins broken out, so it's not listed as HARDWARE port
#define SERIAL_PORT_HARDWARE        Serial1
#define SERIAL_PORT_HARDWARE_OPEN   Serial1

#endif /* _VARIANT_FEATHER_M4_ */

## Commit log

2021-10-19 push MUB v1.0 plus accessory boards
    [KiCad Schematic.kicad_pcb, KiCad Schematic.sch, breakout_pcb.kicad_pcb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]
2021-10-31 export bom and update readme
    [BomV1.csv]
2021-11-01 start arduino package
2022-10-06 arduino version bump
